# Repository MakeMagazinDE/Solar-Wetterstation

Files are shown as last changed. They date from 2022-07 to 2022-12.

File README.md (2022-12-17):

GitHub Logo

Maker Media GmbH
*** 

# Solar-Wetterstation

mißt Leftdruck, -feuchtigkeit, Temperatur, Windgeschwindigkeit und -richtung

### Diese Station wird ganzjährig rund um die Uhr mit Solarstrom betrieben.

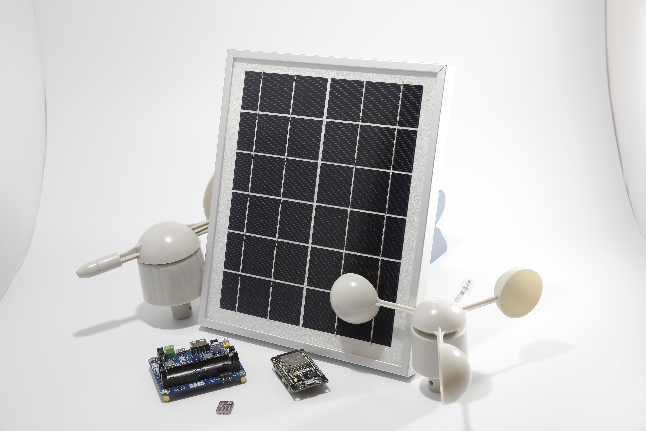
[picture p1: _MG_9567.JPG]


Den vollständigen ersten Teil des Artikels mit der Bauanleitung gibt es in der **[Make-Ausgabe 4/22 ab Seite 32](https://www.heise.de/select/make/2022/4/2216407360229342785) ** zu lesen

Den vollständigen zweiten Teil des Artikels mit der Bauanleitung gibt es in der **[Make-Ausgabe 5/22 ab Seite 58](https://www.heise.de/select/make/2022/5/2221507100729868321) ** zu lesen

Achtung: Die Schaltplanergänzung für den zweiten Teil hat sich geändert. Manche SD-Kartenmodule arbeiten nicht mit 3,3V. Daher müssen diese Module vom Pluspol des Akkuanschlusses auf der Lolin 32 lite versorgt werden!

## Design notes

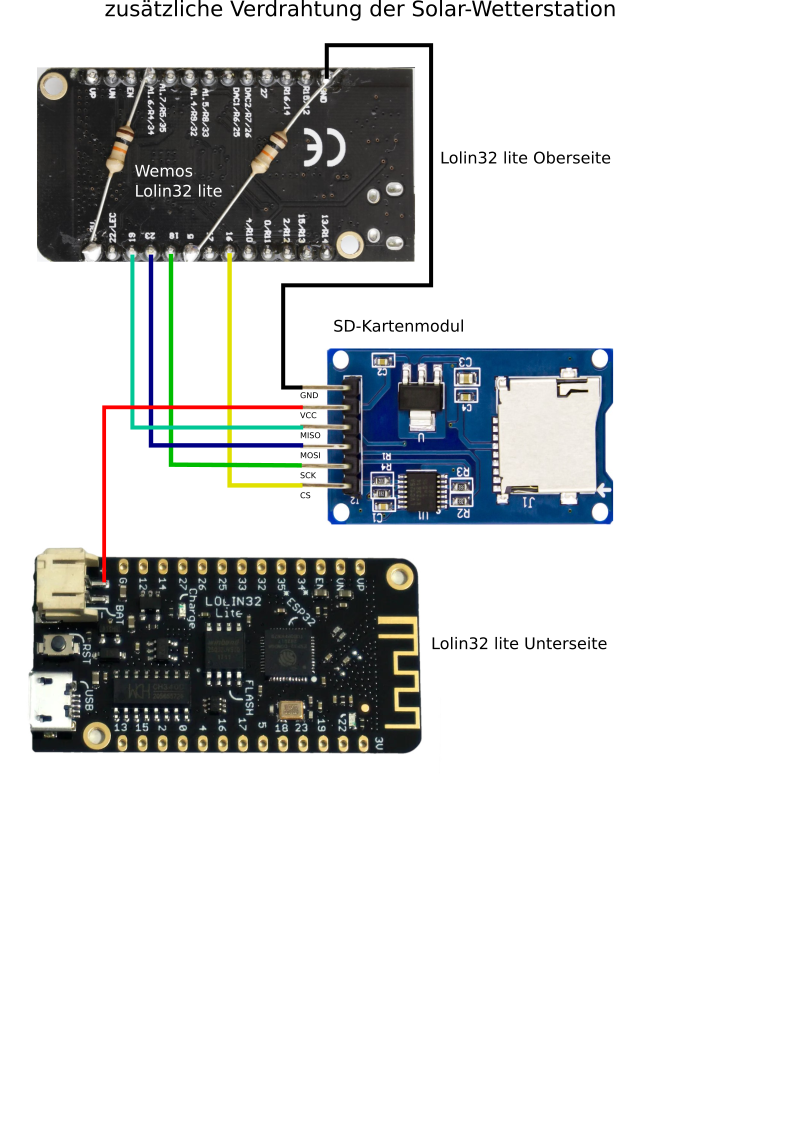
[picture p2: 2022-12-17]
Schaltplan Teil2/SchaltplanV2.png

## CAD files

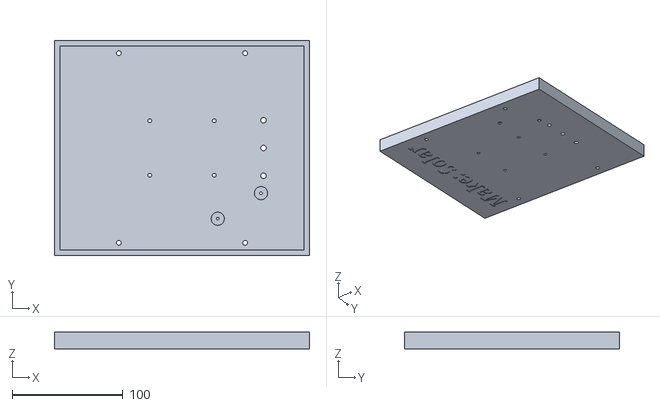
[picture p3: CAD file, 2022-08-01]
3D-Druckdateien/Solarpanelhalter_Rueckwand.stl
230.0 x 194.0 x 15.0

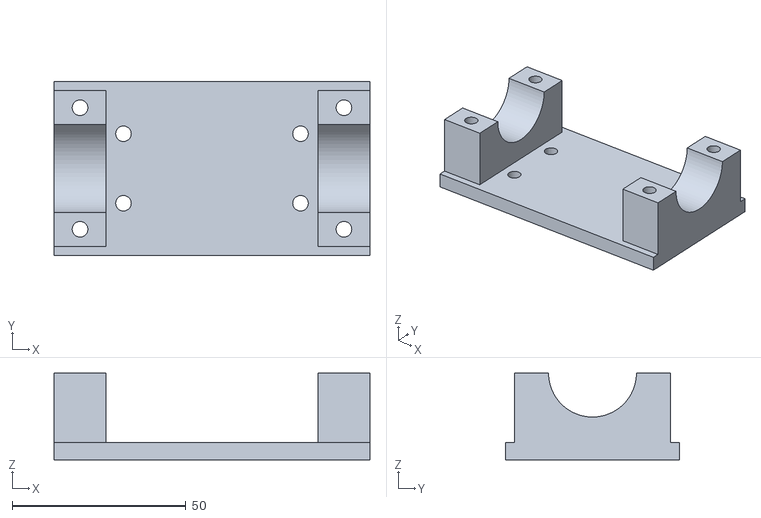
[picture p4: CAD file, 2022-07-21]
3D-Druckdateien/Solarpanelhalterwindrohrhalter.stl
91.0 x 50.0 x 25.0

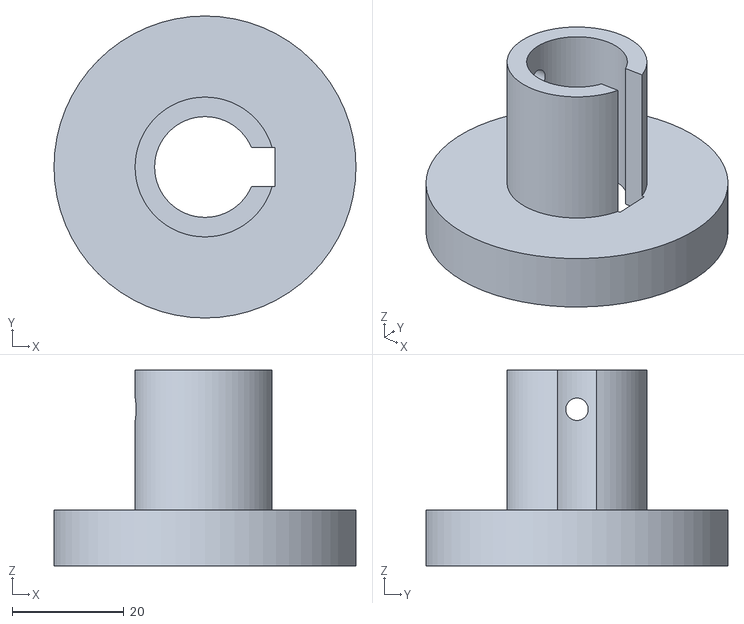
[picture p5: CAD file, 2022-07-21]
3D-Druckdateien/Solarpanelhalter_windrichtung.stl
54.0 x 54.0 x 35.0

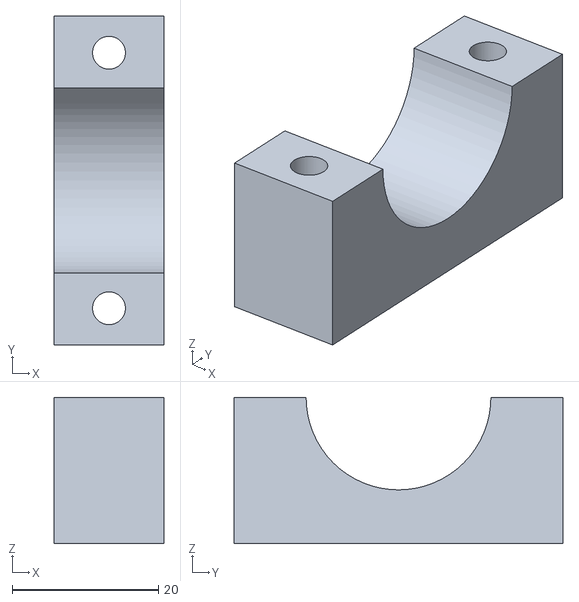
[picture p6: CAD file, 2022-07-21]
3D-Druckdateien/Solarpanelhalter_windrohrschelle.stl
15.0 x 45.0 x 20.0

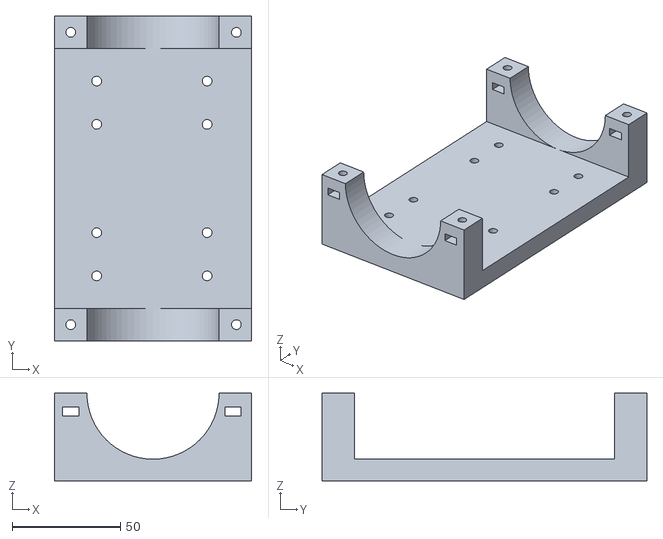
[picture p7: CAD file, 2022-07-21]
3D-Druckdateien/Solarpanelhalter_rohrplatte.stl
91.0 x 150.0 x 40.5

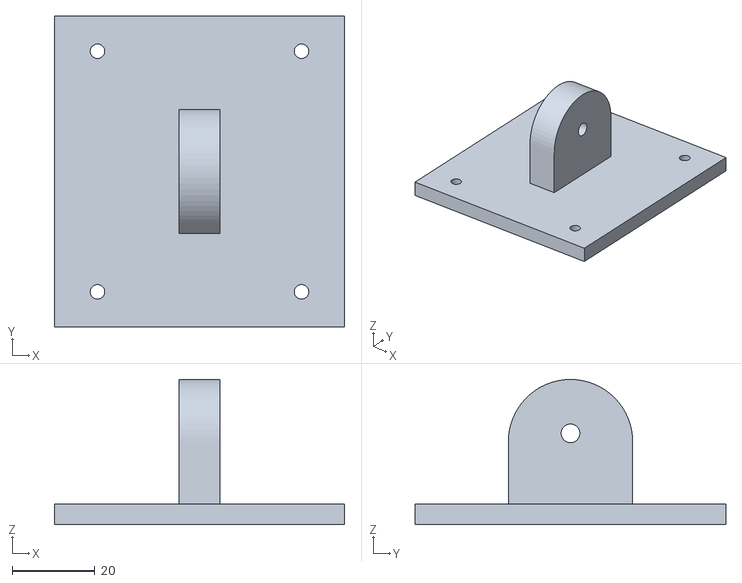
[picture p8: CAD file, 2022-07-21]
3D-Druckdateien/Solarpanelhalter_Panel.stl
70.0 x 75.0 x 35.0

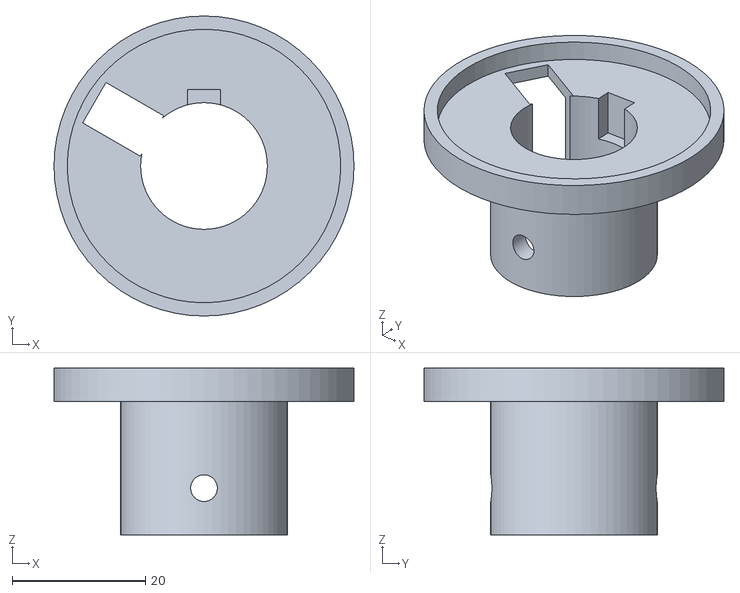
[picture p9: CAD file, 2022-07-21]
3D-Druckdateien/Solarpanelhalter_windgeschwindigkeit.stl
45.0 x 45.0 x 25.0

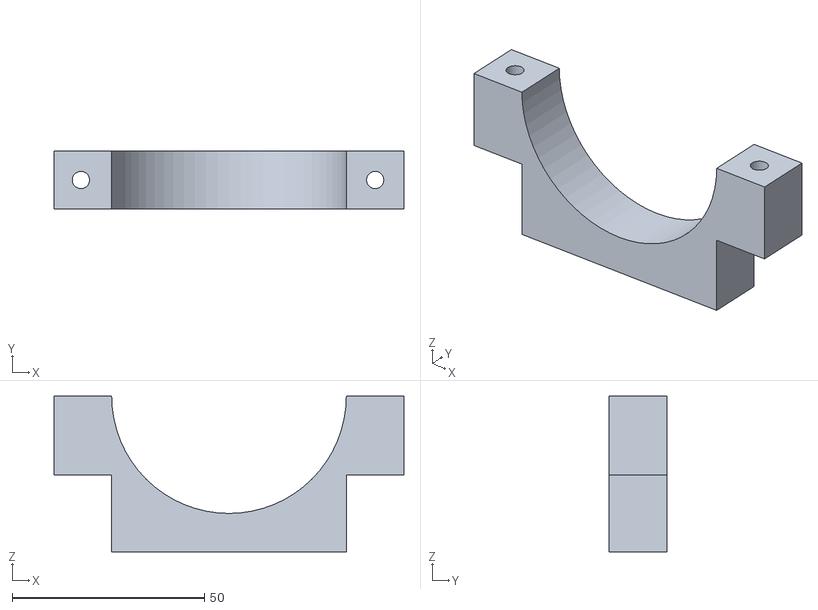
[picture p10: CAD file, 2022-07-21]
3D-Druckdateien/Solarpanelhalter_schelle.stl
91.0 x 15.0 x 40.5

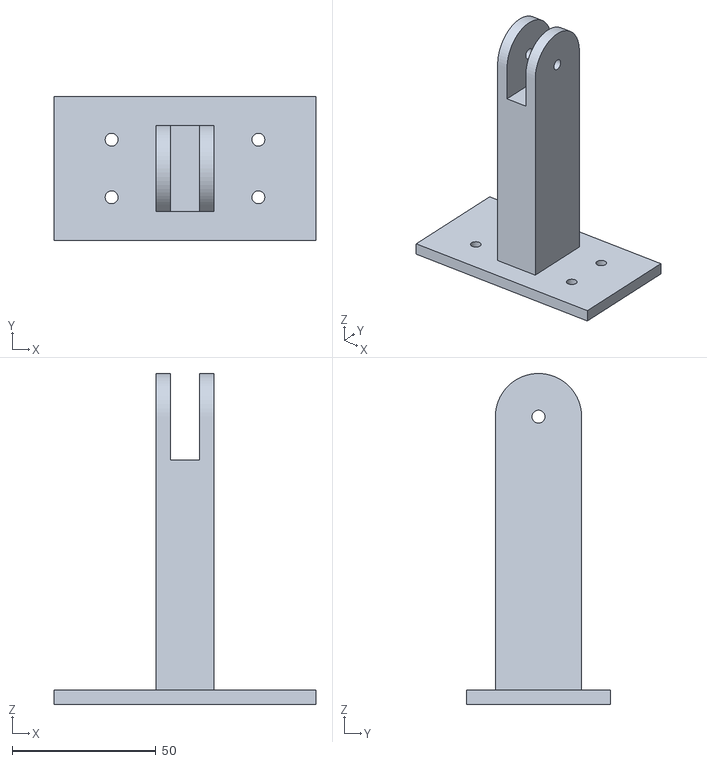
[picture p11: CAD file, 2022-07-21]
3D-Druckdateien/Solarpanelhalter_platte.stl
91.0 x 50.0 x 115.0

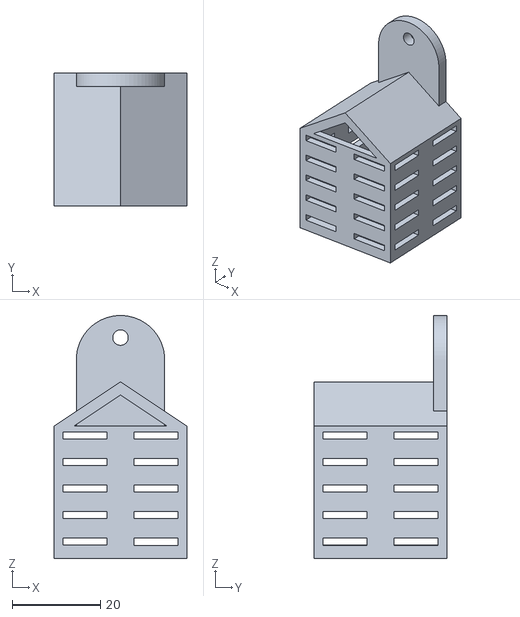
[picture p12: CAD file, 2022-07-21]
3D-Druckdateien/Solarpanelhalter_thermo.stl
30.0 x 30.0 x 55.0

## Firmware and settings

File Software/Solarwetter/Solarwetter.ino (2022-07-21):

#include <Wire.h>
#include <Adafruit_Sensor.h>
#include <Adafruit_BME280.h>
#include <WiFi.h>

const int dirPIN = 34;
const int RecordTime = 3;
const int SensorPin = 5;
const char* ssid = "WLAN-SSID";
const char* password = "WLAN-Passwort";
int dirValue = 0;
int dir;
int InterruptCounter;
float WindSpeed;
char* directions[]={ "Nord", "Nord-Ost", "Ost", "Sued-Ost", "Sued","Sued-West", "West", "Nord-West"};

Adafruit_BME280 bme;
WiFiServer server(80);

void setup() {
  Serial.begin(9600);
  Serial.println();
  Serial.print(F("Connecting to "));
  Serial.println(ssid);
  WiFi.mode(WIFI_STA);
  WiFi.begin(ssid, password);
  while (WiFi.status() != WL_CONNECTED) {
    delay(500);
    Serial.print(F("."));
  }
  Serial.println();
  Serial.println(F("WiFi connected"));
  server.begin();
  Serial.println(F("Server started"));
  Serial.println(WiFi.localIP());
  Serial.println(F("BME280 test"));
  Wire.begin(32, 33);
  bool status;
  status = bme.begin(0x76);  
  if (!status) {
    Serial.println("Kann keinen BME280 finden, Verkabelung prüfen!");
    while (1);
  }
  Serial.println("BME280 ok!");
  Serial.println();
}
void loop() { 
  WiFiClient client = server.available();
  float temperatur = bme.readTemperature();
  float feuchtigkeit = bme.readHumidity();
  float druck = bme.readPressure() / 100.0F;
  float geschwindigkeit = WindSpeed;

  client.print("<head><title>Make-Solarwetter</title><meta http-equiv='refresh' content='5' /></head>");
  client.print("<img src='http://www.heise.de/make/icons/make_logo.png' alt='Make:' height=10%><h1>Solar-Wetter </h1><br>");
  client.print("<table>");
  client.print("<tr><td><b>Temperatur:</b> </td><td>"); client.print(temperatur); client.print(" Grad Celsius<br></td></tr>");
  client.print("<tr><td><b>Luftfeuchtigkeit:</b> </td><td>"); client.print(feuchtigkeit); client.print(" %<br></td></tr>");
  client.print("<tr><td><b>Luftdruck:</b> </td><td>"); client.print(druck); client.print(" hPa<br></td></tr>");
  client.print("<tr><td><b>Windrichtung:</b> </td><td>"); client.print(directions[winddirect()]); client.print("  <br></td></tr>");
  client.print("<tr><td><b>Windgeschwindigkeit:</b> </td><td>"); client.print(geschwindigkeit); client.print(" km/h<br></td></tr>");
  client.print("</table>");

  wind();
}

int winddirect(){
 int dirValue = 0;
  for (int i=0; i<100; i++) {
      dirValue = dirValue + analogRead(dirPIN);
  }
  dirValue = dirValue/100;
  if (dirValue < 230) {
     dir = 0;
  }
  if (dirValue >500 && dirValue < 580) {
     dir = 1;
  }
   if (dirValue >950 && dirValue < 990) {
     dir = 2;
  }
   if (dirValue >2300 && dirValue < 2330) {
     dir = 3;
  }
   if (dirValue >3860 && dirValue < 3890) {
     dir = 4;
  }
   if (dirValue >3460 && dirValue < 3490) {
     dir = 5;
  }
   if (dirValue >2930 && dirValue < 2950) {
     dir = 6;
  }
   if (dirValue >1640 && dirValue < 1670) {
     dir = 7;
  }
  return dir;
}          

void wind() {
  InterruptCounter = 0;
  attachInterrupt(digitalPinToInterrupt(SensorPin), countup, RISING);
  delay(1000 * RecordTime);
  detachInterrupt(digitalPinToInterrupt(SensorPin));
  WindSpeed = (float)InterruptCounter / (float)RecordTime * 2.4;
}

void countup() {
  InterruptCounter++;
}

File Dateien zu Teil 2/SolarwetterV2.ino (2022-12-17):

#include <WiFi.h>
#include <WebServer.h>
#include <Wire.h>
#include <SPI.h>
#include <SD.h>
#include <Adafruit_BME280.h>
#include <Adafruit_Sensor.h>
#include <ArduinoOTA.h>
#include <time.h>

const char *SSID = "Ihr WLAN";
const char *PWD = "WLAN-Passwort";
const char* ntpServer = "pool.ntp.org";
const long  gmtOffset_sec = 3600;
const int   daylightOffset_sec = 3600;
const int RecordTime = 3;
const int SensorPin = 5;
float temperatur = 0;
float feuchtigkeit = 0;
float druck = 0;
float geschwindigkeit = 0;
float WindSpeed;
int dirPIN = 34;
int csPIN = 16;
int richtung = 0;
int InterruptCounter;
int dir;
String buffer1;
String hour;
String minutes;
String seconds;
String year;
String month;
String day;
String page; 
String datestring;
String timestring;
char* directions[]={ "Nord", "Nord-Ost", "Ost", "Sued-Ost", "Sued","Sued-West", "West", "Nord-West"};

Adafruit_BME280 bme;
WebServer server(80);

void setup() {
  Serial.begin(9600);
  Wire.begin(32, 33);
  
  if (!SD.begin(csPIN)) {
    Serial.println("Error, SD Initialization Failed");
    return;
  }
  
   // BME280 starten
  if (!bme.begin(0x76)) {
    Serial.println("Problem mit dem BME280");
  }
  
  connectToWiFi();
  
  ArduinoOTA.onStart([]() {
    String type;
    if (ArduinoOTA.getCommand() == U_FLASH) {
      type = "sketch";
    } else { // U_FS
      type = "filesystem";
    }
    Serial.println("Start updating " + type);
  });
  ArduinoOTA.onEnd([]() {
    Serial.println("\nEnd");
  });
  ArduinoOTA.onProgress([](unsigned int progress, unsigned int total) {
    Serial.printf("Progress: %u%%\r", (progress / (total / 100)));
  });
  ArduinoOTA.onError([](ota_error_t error) {
    Serial.printf("Error[%u]: ", error);
    if (error == OTA_AUTH_ERROR) Serial.println("Auth Failed");
    else if (error == OTA_BEGIN_ERROR) Serial.println("Begin Failed");
    else if (error == OTA_CONNECT_ERROR) Serial.println("Connect Failed");
    else if (error == OTA_RECEIVE_ERROR) Serial.println("Receive Failed");
    else if (error == OTA_END_ERROR) Serial.println("End Failed");
  });
  ArduinoOTA.begin();
  
  // Internet-Zeit holen
  configTime(gmtOffset_sec, daylightOffset_sec, ntpServer);

  //Server-Reaktionen definieren
  server.on("/init", getWebpage);
  server.on("/weather", getWeather);
  server.begin();

}

void loop() {
  ArduinoOTA.handle();
  server.handleClient();
    
  temperatur = bme.readTemperature();  
  feuchtigkeit = bme.readHumidity();
  druck = bme.readPressure() / 100;
  richtung = winddirect();
  wind();

  getTimevars();
  if (seconds == "00" || seconds == "01" || seconds == "02") {
    if (!sdwrite()) {
      Serial.println("Daten nicht in Datei geschrieben!");
    }
    else {
      Serial.println("Daten in Datei geschrieben!");
    }
    delay(3000);
  }
}

//Funktionen definieren

void connectToWiFi() {
  Serial.print("Connecting to ");
  Serial.println(SSID);
  WiFi.begin(SSID, PWD);  
  while (WiFi.status() != WL_CONNECTED) {
    //Serial.println(".");
    delay(500);
  } 
  Serial.print("Connected. IP: ");
  Serial.println(WiFi.localIP());
}
 
void getWebpage() {
  Serial.println("Get Webpage");
  page +="<head><title>Make-Solarwetter</title></head>";
  page +="<img src='http://www.heise.de/make/icons/make_logo.png' alt='Make:' height=10%><h1>Solar-Wetter </h1><br>";
  page +="<table>";
  page +="<tr><td><b>Temperatur:</b> </td><td>"; 
  page +=String(temperatur); 
  page +=" Grad Celsius<br></td></tr>";
  page +="<tr><td><b>Luftfeuchtigkeit:</b> </td><td>"; 
  page +=String(feuchtigkeit); 
  page +=" %<br></td></tr>";
  page +="<tr><td><b>Luftdruck:</b> </td><td>"; 
  page +=String(druck); 
  page +=" hPa<br></td></tr>";
  page +="<tr><td><b>Windrichtung:</b> </td><td>"; 
  page +=String(directions[richtung]); 
  page +="  <br></td></tr>";
  page +="<tr><td><b>Windgeschwindigkeit:</b> </td><td>"; 
  page +=String(geschwindigkeit); 
  page +=" km/h<br></td></tr>";
  page +="</table>";
  server.send(200, "text/html", page);
}
 
void getWeather() {
  Serial.println("Get weather");
  buffer1 ="{\"main\":{\"temp\":";
  buffer1 +=String(temperatur);
  buffer1 +=",\"pressure\":";
  buffer1 +=String(druck);
  buffer1 +=",\"humidity\":";
  buffer1 +=String(feuchtigkeit);
  buffer1 +="},\"wind\":{\"speed\":";
  buffer1 +=String(geschwindigkeit);
  buffer1 +=",\"deg\":";
  buffer1 +=String(45*richtung);
  buffer1 +="}}";
  server.send(200, "application/json", buffer1);
  Serial.println("Gesendetes JSON-Objekt: ");
  Serial.println(buffer1);
}

void wind() {
  InterruptCounter = 0;
  attachInterrupt(digitalPinToInterrupt(SensorPin), countup, RISING);
  delay(1000 * RecordTime);
  detachInterrupt(digitalPinToInterrupt(SensorPin));
  geschwindigkeit = (float)InterruptCounter / (float)RecordTime * 2.4;
}

void countup() {
  InterruptCounter++;
}

int winddirect(){
 int dirValue = 0;
  for (int i=0; i<100; i++) {
      dirValue = dirValue + analogRead(dirPIN);
  }
  dirValue = dirValue/100;
  if (dirValue < 230) {
     dir = 0;
  }
  if (dirValue >500 && dirValue < 580) {
     dir = 1;
  }
   if (dirValue >950 && dirValue < 990) {
     dir = 2;
  }
   if (dirValue >2300 && dirValue < 2330) {
     dir = 3;
  }
   if (dirValue >3860 && dirValue < 3890) {
     dir = 4;
  }
   if (dirValue >3460 && dirValue < 3490) {
     dir = 5;
  }
   if (dirValue >2930 && dirValue < 2950) {
     dir = 6;
  }
   if (dirValue >1640 && dirValue < 1670) {
     dir = 7;
  }
  return dir;
}   

void getTimevars(){
  struct tm timeinfo;
  if(!getLocalTime(&timeinfo)){
    Serial.println("Failed to obtain time");
    return;
  }
  char timevar[5];
  strftime(timevar,3, "%H", &timeinfo);
  hour = timevar;
  strftime(timevar,3, "%M", &timeinfo);
  minutes = timevar;
  strftime(timevar,3, "%S", &timeinfo);
  seconds = timevar;
  strftime(timevar,5, "%Y", &timeinfo);
  year = timevar;
  strftime(timevar,5, "%b", &timeinfo);
  month = timevar;
  strftime(timevar,3, "%d", &timeinfo);
  day = timevar;
  datestring = day + "." + month + "." + year;
  timestring = hour + ":" + minutes + ":" + seconds;
}
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
